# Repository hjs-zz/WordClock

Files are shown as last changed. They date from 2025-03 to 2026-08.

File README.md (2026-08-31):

# WordClock

Arduino-Wortuhr mit 110 NeoPixel-LEDs, DS3231-Echtzeituhr und Taster zur
Farbauswahl.

Der Sketch ist in unabhängige Module für Zeit, Wortlogik und Anzeige
aufgeteilt. Alle Animationen laufen ohne blockierende `delay()`-Aufrufe, damit
Taster und RTC auch während eines Übergangs verarbeitet werden.

## Zeitbasis

Die DS3231 wird in **UTC** geführt. Der Sketch rechnet die Zeit automatisch in
deutsche Ortszeit (MEZ/UTC+1 bzw. MESZ/UTC+2) um. Die Sommerzeit beginnt am
letzten Sonntag im März und endet am letzten Sonntag im Oktober.

Bei einer neuen oder falsch gestellten RTC kann in `setup()` einmalig
`clockService.setFromLocalCompileTime(__DATE__, __TIME__)` aktiviert werden.
Danach die Zeile wieder
auskommentieren und erneut übertragen, damit die RTC bei späteren Neustarts
nicht auf den Kompilierungszeitpunkt zurückgesetzt wird. Die Systemzeit des
Rechners muss dabei auf deutsche Ortszeit eingestellt sein.

Der Sketch prüft beim Start und danach regelmäßig das Oscillator-Stop-Flag der
RTC. Bei einer ungültigen Uhrzeit blinken die vier Eck-LEDs rot. Nach einer
erfolgreichen Initialisierung nimmt die normale Anzeige automatisch ihren
Betrieb wieder auf.

## Bedienung

Der Taster an Pin 2 wechselt zwischen Weiß, Rot, Grün und Blau. Die Auswahl
wird im EEPROM gespeichert.

Die globale LED-Helligkeit ist in `Config.h` auf 255 eingestellt. Die frühere
Reverse-Shuffle-Animation wurde entfernt, damit keine Animation alle 110 LEDs
gleichzeitig einschaltet. Netzteil, Leitungsquerschnitt und Stromeinspeisung
müssen trotzdem für die maximale Helligkeit der sichtbaren Wörter ausgelegt
sein.

## Projektstruktur

- `WordClock_copy_20250322140103.ino`: Initialisierung und Hauptschleife
- `Config.h`: Pins, Helligkeit und Zeitintervalle
- `ClockLogic.*`: Übersetzung einer Uhrzeit in LED-Wörter
- `RtcClock.*`: UTC, deutsche Ortszeit und RTC-Zustand
- `LedDisplay.*`: Farben, Fehleranzeige und nicht blockierende Animationen

## Hardware

- Arduino Uno
- DS3231 RTC (SDA: A4, SCL: A5)
- 110 NeoPixel-LEDs (Datenleitung: Pin 8)
- Taster gegen GND (Pin 2 mit internem Pull-up)
- geregeltes 5-V-Netzteil mit mindestens 3 A bei der voreingestellten Helligkeit
- 330–470-Ω-Widerstand in der Datenleitung
- 1.000-µF-Pufferkondensator an der LED-Einspeisung

Analogpin A0 bleibt unbeschaltet und dient als Zufallsquelle für die
Animationsreihenfolge.

Der vollständige, sicherheitsrelevante Verdrahtungsvorschlag steht im
[`Anschlussplan.txt`](Anschlussplan.txt). Insbesondere werden die LEDs direkt
vom Netzteil und nicht über den Arduino versorgt. Alle Komponenten benötigen
eine gemeinsame Masse.

## Todo

- [ ] Geregeltes 5-V-/3-A-Netzteil auswählen und unter Last prüfen
- [ ] 2,5–3-A-Sicherung in den LED-Versorgungszweig integrieren
- [ ] 1.000-µF-Kondensator nahe der ersten LED montieren
- [ ] 330–470-Ω-Widerstand nahe DIN der ersten LED montieren
- [ ] Zweite 5-V-/GND-Einspeisung in der Mitte oder am Ende ergänzen
- [ ] Ausreichenden Leitungsquerschnitt, feste Klemmen und Zugentlastung vorsehen
- [ ] RTC-Modul auf Pull-ups, Ladeschaltung und passenden Batterietyp prüfen
- [ ] CAD für LED-Platte fertigstellen
- [ ] Halterung für RTC in die Deckplatte integrieren
- [ ] Frontplatte individualisierbar machen

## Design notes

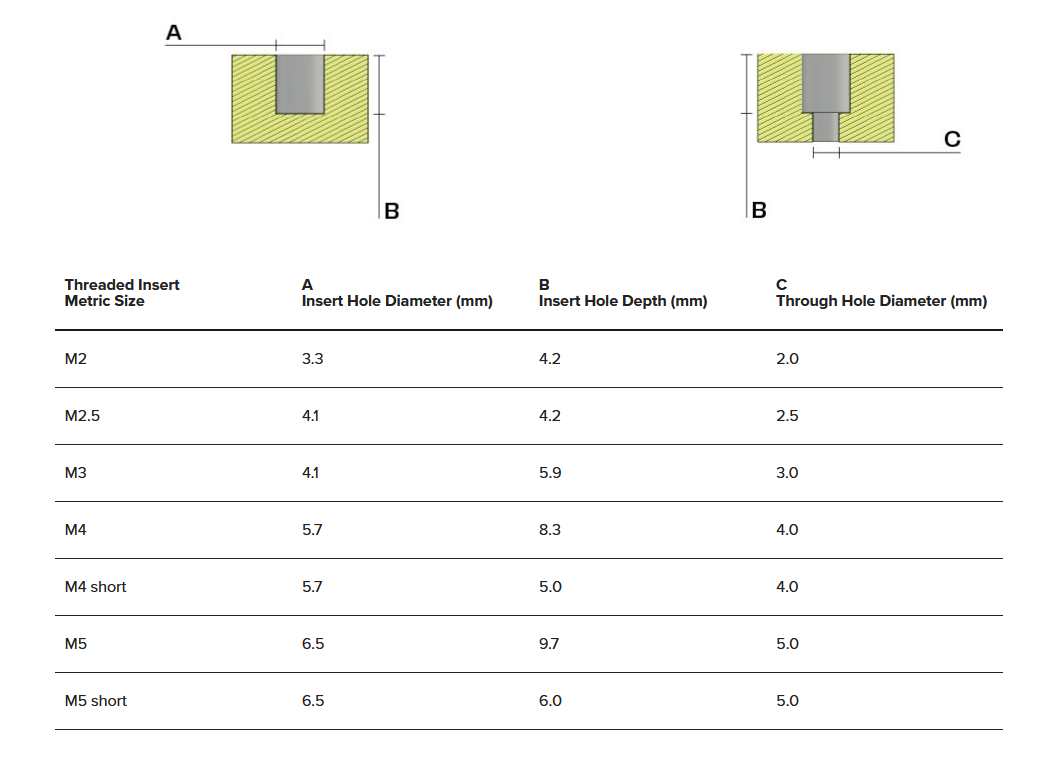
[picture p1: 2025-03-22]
CAD/files/Heat Insets.PNG

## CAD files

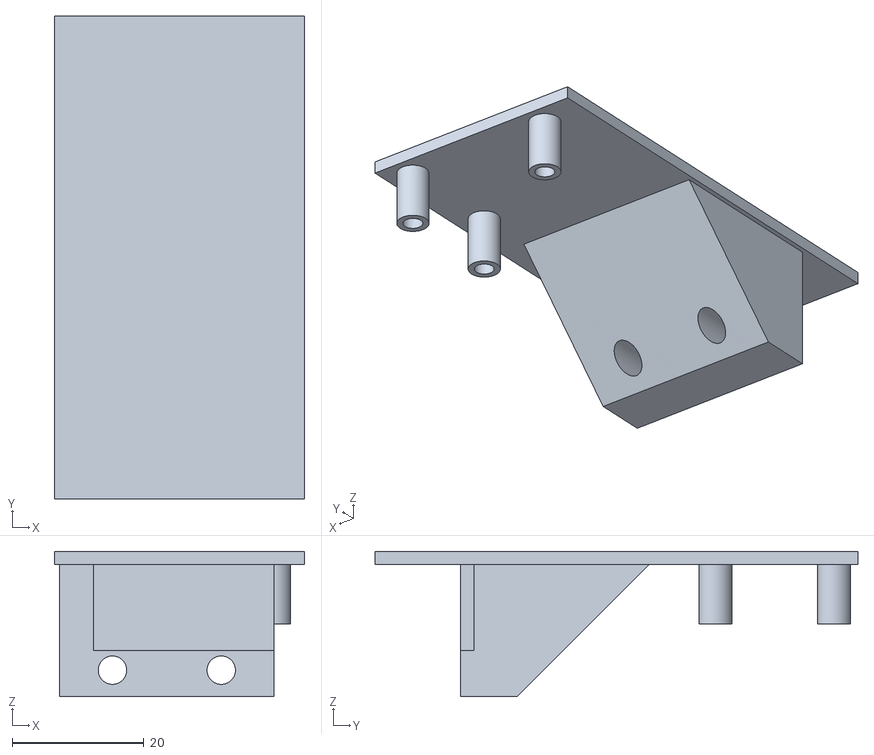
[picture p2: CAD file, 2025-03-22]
CAD/files/Back_Plate_Test.STL
38.0 x 73.2 x 22.0

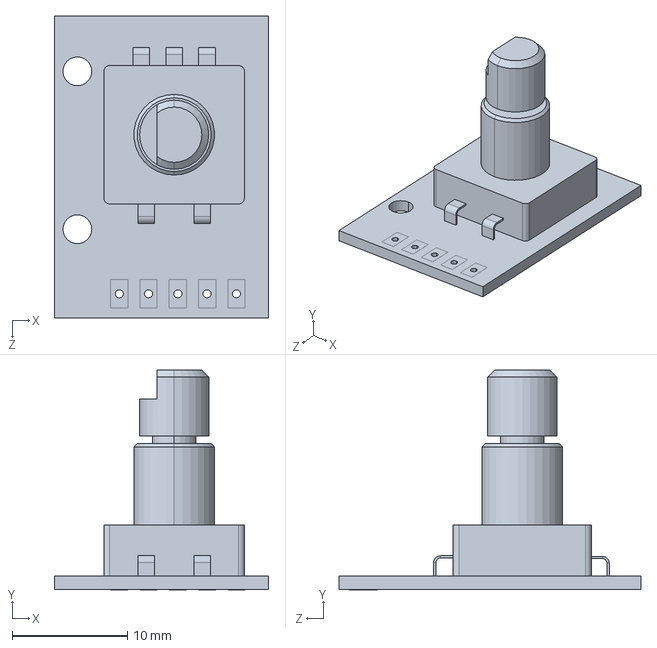
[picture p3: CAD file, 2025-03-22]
CAD/files/Encoder KY-040.SLDPRT
18.6 x 19.1 x 26.2 mm

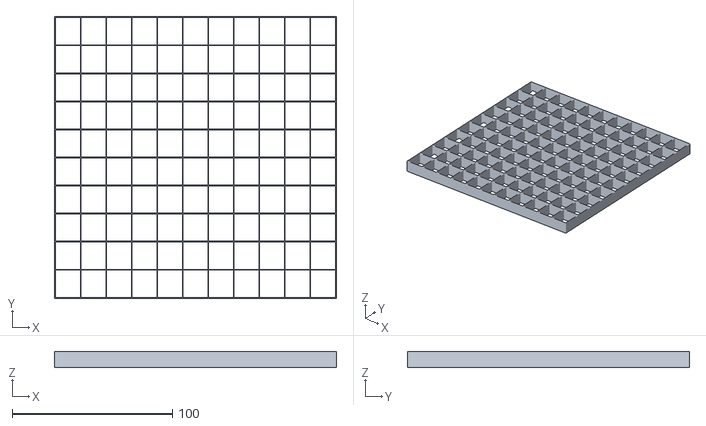
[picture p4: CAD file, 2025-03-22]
CAD/files/Light_Seperator.stl
176.0 x 176.0 x 10.0

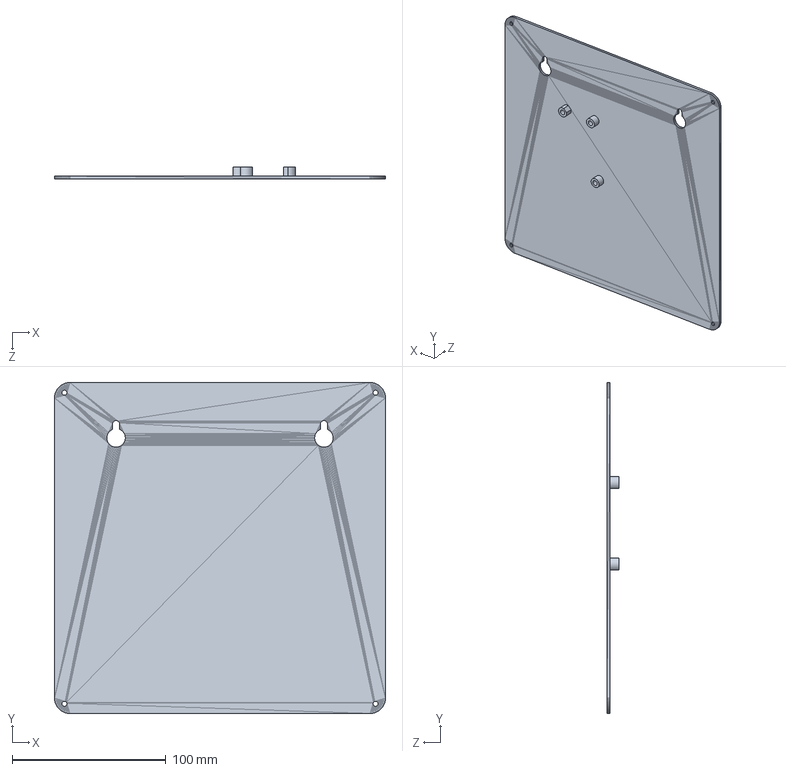
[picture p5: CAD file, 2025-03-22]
CAD/files/Back_Plate.SLDPRT
215.0 x 215.0 x 8.00 mm

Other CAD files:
CAD/files/Back_Plate.STL

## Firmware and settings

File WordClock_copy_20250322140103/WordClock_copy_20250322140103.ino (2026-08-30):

#include <EEPROM.h>
#include <Wire.h>

#include "ClockLogic.h"
#include "Config.h"
#include "LedDisplay.h"
#include "RtcClock.h"

LedDisplay display;
RtcClock clockService;
DisplayState currentDisplay;

volatile bool buttonPressed = false;
uint8_t colorState = 0;
int lastDisplayKey = -1;
bool rtcValid = false;
bool errorVisible = false;
unsigned long lastButtonPress = 0;
unsigned long lastClockRefresh = 0;
unsigned long lastRtcCheck = 0;
unsigned long lastErrorToggle = 0;

void onButtonPressed() {
  buttonPressed = true;
}

void handleButton(unsigned long now) {
  noInterrupts();
  const bool wasPressed = buttonPressed;
  buttonPressed = false;
  interrupts();

  if (!wasPressed) {
    return;
  }

  if (lastButtonPress != 0 &&
      now - lastButtonPress < Config::BUTTON_DEBOUNCE_MS) {
    return;
  }

  lastButtonPress = now;
  colorState = (colorState + 1) % Config::COLOR_COUNT;
  EEPROM.update(Config::COLOR_EEPROM_ADDRESS, colorState);
  display.setColor(colorState);

  if (rtcValid) {
    display.redrawTarget();
  }
}

void checkRtc(unsigned long now) {
  if (now - lastRtcCheck < Config::RTC_CHECK_MS) {
    return;
  }
  lastRtcCheck = now;

  const bool wasValid = rtcValid;
  rtcValid = clockService.isValid();

  if (rtcValid == wasValid) {
    return;
  }

  if (rtcValid) {
    Serial.println(F("RTC is running again."));
    lastDisplayKey = -1;
  } else {
    Serial.println(F("RTC error: oscillator stopped or time is invalid."));
    display.showRtcError(true);
    errorVisible = true;
  }
}

void updateRtcError(unsigned long now) {
  if (now - lastErrorToggle < Config::ERROR_BLINK_MS) {
    return;
  }

  lastErrorToggle = now;
  errorVisible = !errorVisible;
  display.showRtcError(errorVisible);
}

void updateClock(unsigned long now) {
  if (now - lastClockRefresh < Config::CLOCK_REFRESH_MS) {
    return;
  }
  lastClockRefresh = now;

  const time_t localNow = clockService.localNow();
  buildDisplayState(currentDisplay, hour(localNow), minute(localNow));

  if (currentDisplay.key != lastDisplayKey) {
    display.startRandomTransition(currentDisplay.leds);
    lastDisplayKey = currentDisplay.key;
  }
}

void setup() {
  Serial.begin(57600);
  Wire.begin();

  display.begin();
  colorState = EEPROM.read(Config::COLOR_EEPROM_ADDRESS);
  if (colorState >= Config::COLOR_COUNT) {
    colorState = 0;
  }
  display.setColor(colorState);

  randomSeed(analogRead(Config::RANDOM_SEED_PIN) ^ micros());

  pinMode(Config::BUTTON_PIN, INPUT_PULLUP);
  attachInterrupt(digitalPinToInterrupt(Config::BUTTON_PIN), onButtonPressed,
                  FALLING);

  // Enable once to initialize a new or invalid RTC, upload, then comment again:
  // clockService.setFromLocalCompileTime(__DATE__, __TIME__);

  rtcValid = clockService.isValid();
  const unsigned long now = millis();
  lastRtcCheck = now;
  lastClockRefresh = now - Config::CLOCK_REFRESH_MS;

  if (rtcValid) {
    Serial.println(F("Word clock ready."));
  } else {
    Serial.println(F("RTC error: initialize the clock before normal use."));
    display.showRtcError(true);
    errorVisible = true;
  }
}

void loop() {
  const unsigned long now = millis();

  handleButton(now);
  display.update(now);
  checkRtc(now);

  if (rtcValid) {
    updateClock(now);
  } else {
    updateRtcError(now);
  }
}

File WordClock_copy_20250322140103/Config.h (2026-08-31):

#pragma once

#include <Arduino.h>

namespace Config {
constexpr uint8_t BUTTON_PIN = 2;
constexpr uint8_t LED_PIN = 8;
constexpr uint8_t RANDOM_SEED_PIN = A0;
constexpr uint16_t LED_COUNT = 110;

// Full brightness is safe with the current transitions because no animation
// switches on the complete 110-pixel matrix at once.
constexpr uint8_t LED_BRIGHTNESS = 255;
constexpr uint8_t COLOR_COUNT = 4;
constexpr uint8_t COLOR_EEPROM_ADDRESS = 0;

constexpr unsigned long BUTTON_DEBOUNCE_MS = 250;
constexpr unsigned long CLOCK_REFRESH_MS = 1000;
constexpr unsigned long RTC_CHECK_MS = 10000;
constexpr unsigned long ERROR_BLINK_MS = 500;
}  // namespace Config

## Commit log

2026-08-30 Refactor word clock and fix timezone handling
    [Config.h, WordClock_copy_20250322140103.ino]
2026-08-30 Document safer hardware wiring and todos
2026-08-31 Increase LED brightness and remove full-matrix animation
